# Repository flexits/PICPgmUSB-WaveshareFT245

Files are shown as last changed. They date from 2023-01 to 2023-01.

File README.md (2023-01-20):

## PICPgm USB Programmer на основе модуля Waveshare FT245 USB FIFO Board (mini)

Схема и печатная плата программатора в KiCAD 6.  
Плата односторонняя для DIY.
Сделано на скорую руку для собственного использования, проверено с контроллером PIC12F1840, читает и пишет без проблем.  
ИМС `74LS14N` в моей реализации заменена на `К555ТЛ2` (просто потому что была в наличии); также вместо неё должны работать и более новая `КР1533ТЛ2`, и более старая `К155ТЛ2`.
### Erratum
- Разводка платы не оптимальна.  
- Также напутал с нумерацией контактов разъёма под Waveshare board, из-за чего в проекте пришлось поставить его на стороне дорожек. В реальности, конечно же, разъём припаивается как и положено, на лицевую сторону платы.  
- Пожалуй, имеет смысл входы неиспользуемых триггеров подтянуть к питанию, а не к земле.
- Пожалуй, привычнее будет плату отзеркалить, чтоб USB был слева, а панелька — справа, но это уже дело вкуса и конфигурации рабочего места. 
### Ссылки
Сайт проекта [PICPgm](http://picpgm.picprojects.net/index.html), там же утилита для работы с программатором.  
Драйвер FTDI D2xx [оф. сайт](https://ftdichip.com/drivers/d2xx-drivers/) (впрочем, на моём ПК с Win 10 установился автоматом).  

  


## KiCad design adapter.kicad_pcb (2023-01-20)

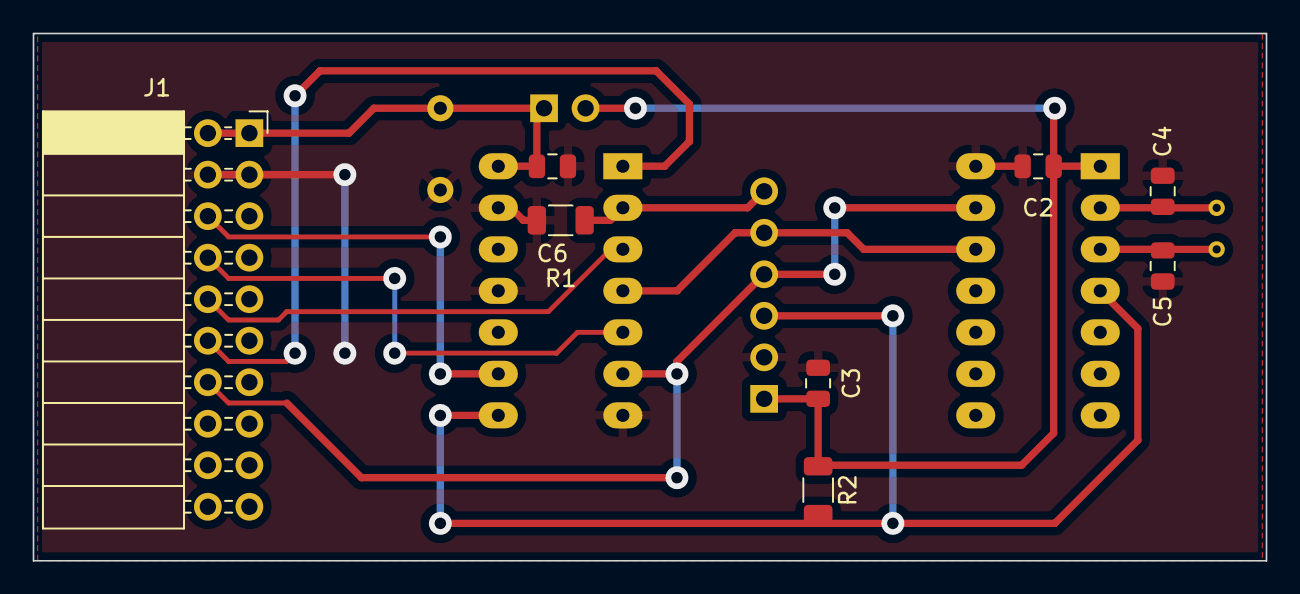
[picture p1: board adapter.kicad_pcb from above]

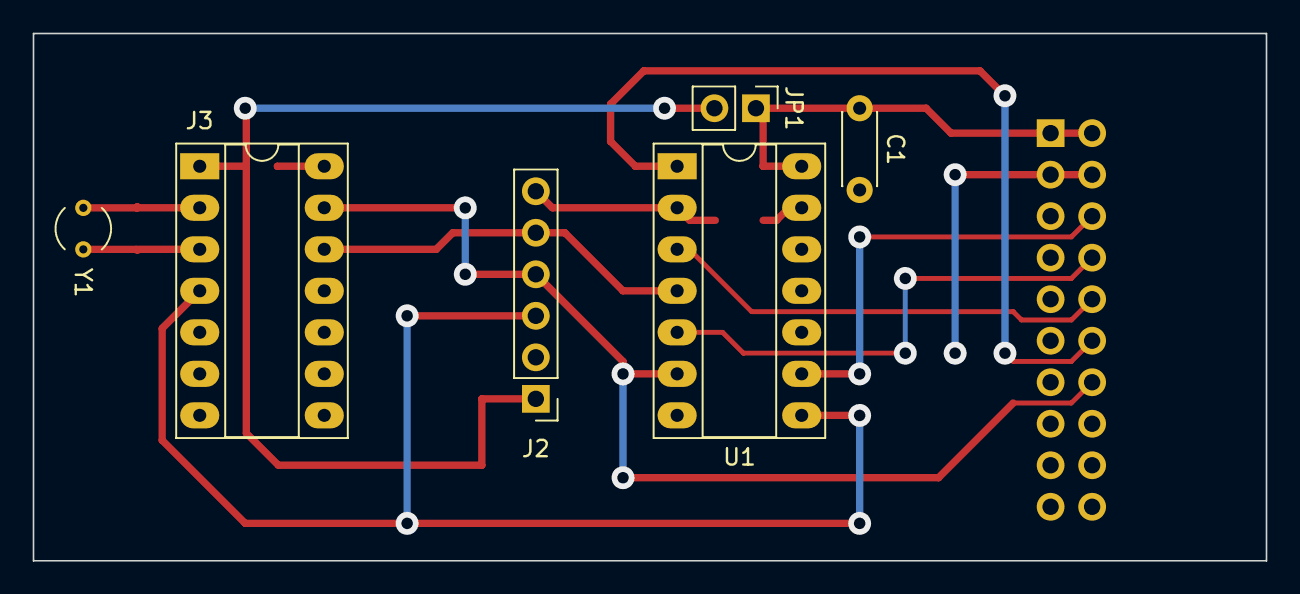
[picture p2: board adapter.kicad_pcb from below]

Board: 2 copper layers, 75.4 x 32.3 mm, 14 parts (6 on the bottom side), 13 nets.

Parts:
C1: 100n; C_Disc_D4.3mm_W1.9mm_P5.00mm
C2, C3, C6: 100n; C_0805_2012Metric
C4, C5: 22p; C_0805_2012Metric
J1: PBD-20R; PinSocket_2x10_P2.54mm_Horizontal
J2: PLS-6; PinHeader_1x06_P2.54mm_Vertical
J3: DS1044-14 panel; DIP-14_W7.62mm_Socket_LongPads
JP1: PLS-2; PinHeader_1x02_P2.54mm_Vertical
R1: 1k; R_1206_3216Metric
R2: 10k; R_1206_3216Metric
U1: 74LS14; DIP-14_W7.62mm_Socket_LongPads
Y1: Crystal; Crystal_AT310_D3.0mm_L10.0mm_Vertical

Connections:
+5V: C2.1, C3.1, J2.1, J3.1, JP1.2 (B), R2.1
GND: C1.2, C2.2, C3.2, C4.2, C5.2, C6.2, J1.3, J1.4, J2.2, J3.14, R1.1, U1.7 (GND), U1.11, U1.13
MCLR: J2.3, J3.4, R2.2, U1.8
unnamed: C4.1, J3.2, Y1.1
unnamed: C5.1, J3.3, Y1.2
unnamed: J1.8, U1.5
unnamed: J1.10, U1.3
unnamed: J1.12, U1.1
unnamed: J1.6, U1.9
PGC: J2.5, J3.12, U1.4
PGD: J1.14, J2.4, J3.13, U1.6
PGM: J2.6, R1.2, U1.2
VCC: C1.1, C6.1, J1.1, J1.2, JP1.1 (A), U1.14 (VCC)
